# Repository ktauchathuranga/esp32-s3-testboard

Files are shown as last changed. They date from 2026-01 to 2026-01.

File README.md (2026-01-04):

# ESP32-S3 Test Board

A custom-designed development board for the ESP32-S3, designed in KiCad. This project was created for learning and prototyping purposes, featuring USB-C connectivity and a compact form factor.

<p align="center">
  <img src="/esp32-s3-testboard/esp32-s3-testboard.png" alt="3D Front View"">
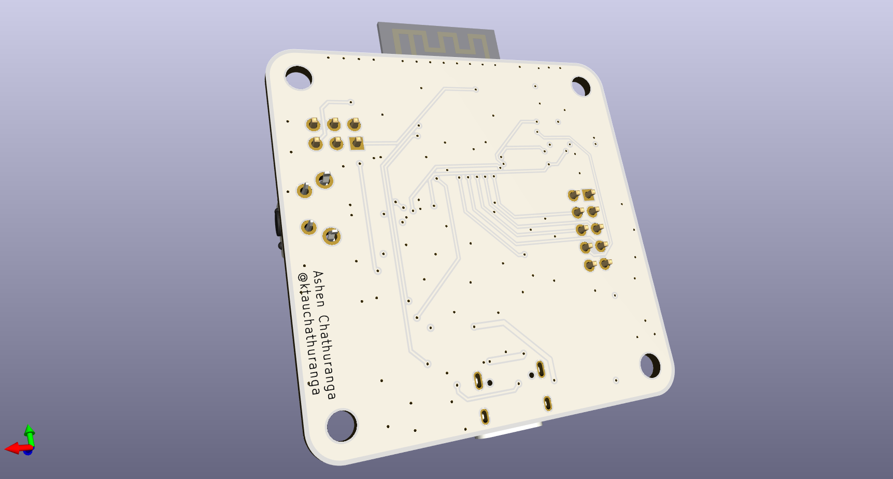
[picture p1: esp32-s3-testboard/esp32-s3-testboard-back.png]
3D Back View
  
</p>

## About The Project

This PCB is a breakout and test board for the **ESP32-S3** microcontroller. It breaks out the necessary pins for prototyping and includes essential circuitry for power management and programming.

The design is based on the [High Speed PCB Design tutorial by Made by Morten](https://www.youtube.com/watch?v=QoU0WWNgO2g).

### Key Features
* **Microcontroller:** ESP32-S3 (WROOM Module)
* **Connectivity:** USB Type-C (Native USB)
* **Power:** Onboard 3.3V LDO Regulator
* **User Interface:** Reset & Boot buttons, Status LEDs
* **Layer Stack:** 4-Layer PCB design for better signal integrity and power distribution

## EDA Tool & Libraries

* **Designed in:** [KiCad EDA](https://www.kicad.org/)
* **Custom Library:** This project utilizes specific footprints and symbols from my personal library:
    * [Oddibits - KiCad Library](https://github.com/ktauchathuranga/oddibits)

## Getting Started

To view or modify the design:

1.  Clone this repository:
    ```bash
    git clone https://github.com/ktauchathuranga/esp32-s3-testboard.git
    ```
2.  Clone the dependency library (Oddibits) alongside it or add it to your KiCad Global Libraries table:
    ```bash
    git clone https://github.com/ktauchathuranga/oddibits.git
    ```
3.  Open the `.kicad_pro` file in KiCad 7.0 or later.

## Fabrication

This board is designed to be manufactured by standard PCB fabrication houses (e.g., JLCPCB, PCBWay).
* **Layers:** 4
* **Minimum Trace/Space:** Check Design Rules (usually 0.2mm or similar standard capabilities)
* **Via Size:** Standard

## Credits & References

* **Original Guide:** [Made by Morten - ESP32-S3 PCB Design](https://www.youtube.com/watch?v=QoU0WWNgO2g)
* **Espressif Systems:** For the ESP32-S3 Datasheets and Hardware Design Guidelines.

## License

This project is open-source. Please see the [LICENSE](LICENSE) file for more details.

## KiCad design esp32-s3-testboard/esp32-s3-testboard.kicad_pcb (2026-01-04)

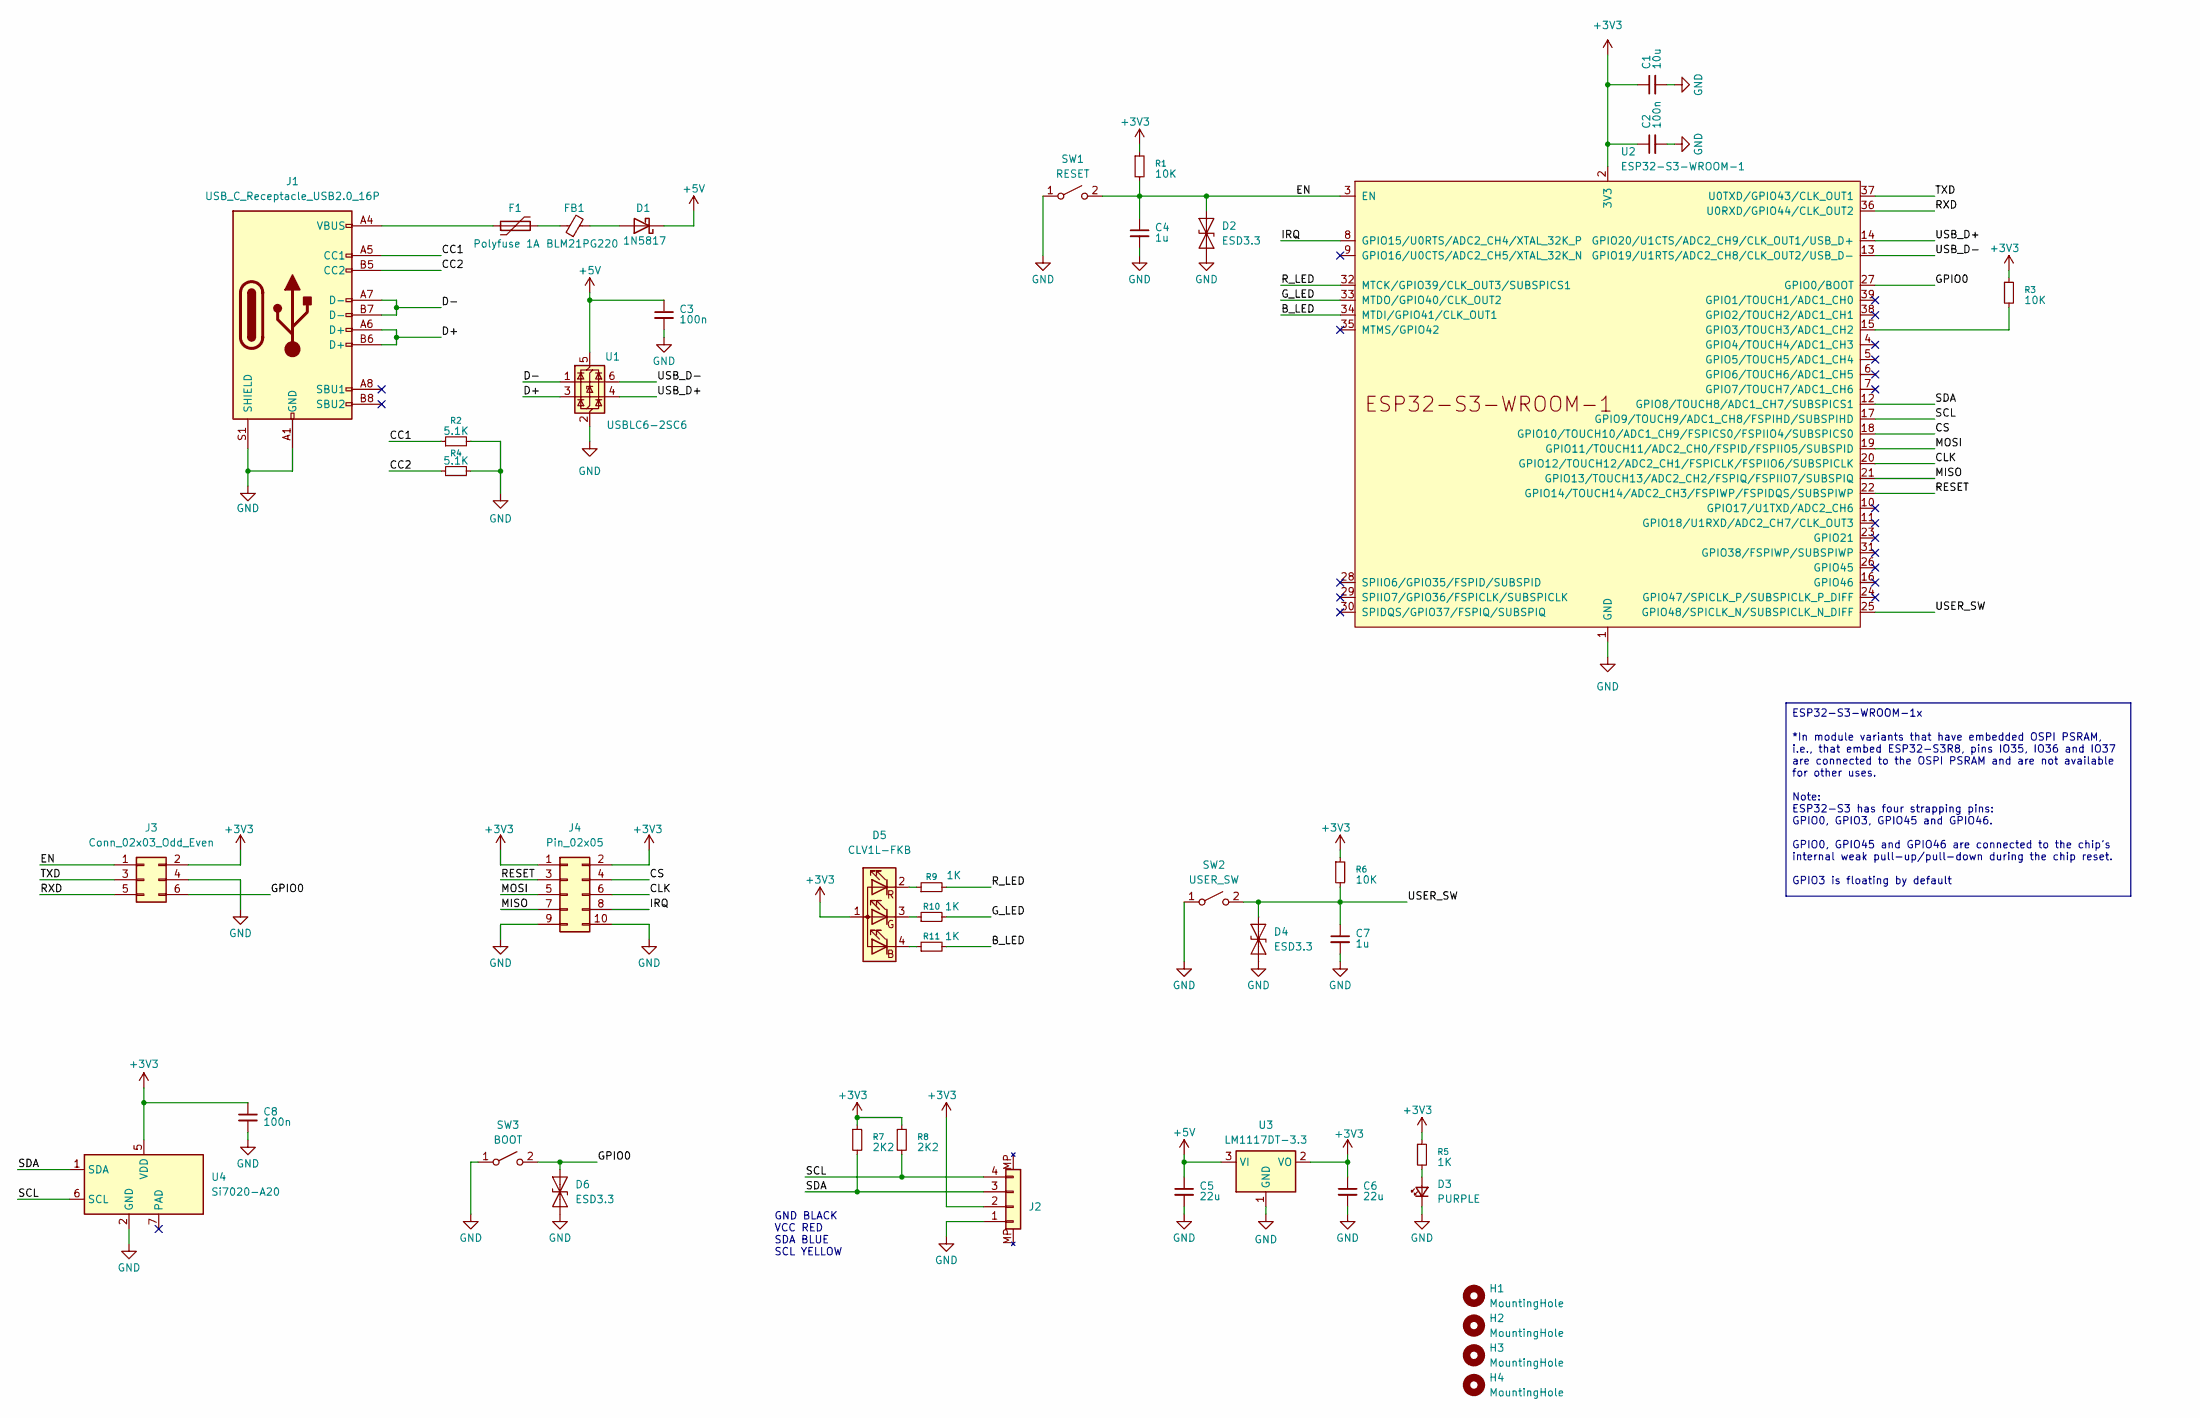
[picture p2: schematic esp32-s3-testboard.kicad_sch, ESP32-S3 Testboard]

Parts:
C1: 10u; C_0603_1608Metric
C2, C3, C8: 100n; C_0402_1005Metric
C4, C7: 1u; C_0603_1608Metric
C5, C6: 22u; C_0805_2012Metric
D1: 1N5817; D_SOD-123
D2, D4, D6: ESD3.3; D_SOD-923
D3: PURPLE; LED_0603_1608Metric
D5: CLV1L-FKB; LED_Cree-PLCC4_3.2x2.8mm_CCW
F1: Polyfuse 1A; Fuse_1206_3216Metric
FB1: BLM21PG220; L_0805_2012Metric
H1, H2, H3, H4: MountingHole; MountingHole_3.2mm_M3
J1: USB_C_Receptacle_USB2.0_16P; USB_C_Receptacle_GCT_USB4105-xx-A_16P_TopMnt_Horizontal
J2: JST_SH_SM04B-SRSS-TB_1x04-1MP_P1.00mm_Horizontal
J3: Conn_02x03_Odd_Even; PinHeader_2x03_P2.54mm_Vertical
J4: Pin_02x05; PinHeader_2x05_P2.54mm_Vertical
R1, R3, R6: 10K; R_0402_1005Metric
R2, R4: 5.1K; R_0402_1005Metric
R5, R9, R10, R11: 1K; R_0402_1005Metric
R7, R8: 2K2; R_0402_1005Metric
SW1: RESET; SW_SPST_B3U-1100P
SW2: USER_SW; SW_Tactile_SPST_Angled_PTS645Vx31-2LFS
SW3: BOOT; SW_SPST_B3U-1100P
U1: USBLC6-2SC6; SOT-23-6
U2: ESP32-S3-WROOM-1
U3: LM1117DT-3.3; SOT-223-3_TabPin2
U4: Si7020-A20; DFN-6-1EP_3x3mm_P1mm_EP1.5x2.4mm

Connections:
+3V3: C1.1, C2.1, C6.1, C8.1, D5.1 (A), J2.2, J3.2, J4.1, J4.2, R1.1, R3.1, R5.1, R6.1, R7.1, R8.1, U2.2 (3V3), U3.2 (VO), U4.5 (VDD); also elsewhere on the board
+5V: C3.1, C5.1, D1.1 (K), U1.5 (VBUS), U3.3 (VI)
/B_LED: R11.2, U2.34 (MTDI/GPIO41/CLK_OUT1)
/CC1: J1.A5 (CC1), R2.1
/CC2: J1.B5 (CC2), R4.1
/CLK: J4.6, U2.20 (GPIO12/TOUCH12/ADC2_CH1/FSPICLK/FSPIIO6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)
/CS: J4.4, U2.18 (GPIO10/TOUCH10/ADC1_CH9/FSPICS0/FSPIIO4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)
/D+: J1.A6 (D+), J1.B6 (D+), U1.3 (I/O2)
/D-: J1.A7 (D-), J1.B7 (D-), U1.1 (I/O1)
/EN: C4.1, D2.2 (A2), J3.1, R1.2, SW1.2 (B), U2.3 (EN); also elsewhere on the board
/GPIO0: D6.2 (A2), J3.6, SW3.2 (B), U2.27 (GPIO0/BOOT); also elsewhere on the board
/G_LED: R10.2, U2.33 (MTDO/GPIO40/CLK_OUT2)
/IRQ: J4.8, U2.8 (GPIO15/U0RTS/ADC2_CH4/XTAL_32K_P)
/MISO: J4.7, U2.21 (GPIO13/TOUCH13/ADC2_CH2/FSPIQ/FSPIIO7/S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)
/MOSI: J4.5, U2.19 (GPIO11/TOUCH11/ADC2_CH0/FSPID/FSPIIO5/S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)
/RESET: J4.3, U2.22 (GPIO14/TOUCH14/ADC2_CH3/FSPIWP/FSPIDQS/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)
/RXD: J3.5, U2.36 (U0RXD/GPIO44/CLK_OUT2); also elsewhere on the board
/R_LED: R9.2, U2.32 (MTCK/GPIO39/CLK_OUT3/SUBSPICS1)
/SCL: J2.4, R8.2, U2.17 (GPIO9/TOUCH9/ADC1_CH8/FSPIHD/SUBSPIHD), U4.6 (SCL)
/SDA: J2.3, R7.2, U2.12 (GPIO8/TOUCH8/ADC1_CH7/SUBSPICS1), U4.1 (SDA)
/TXD: J3.3, U2.37 (U0TXD/GPIO43/CLK_OUT1); also elsewhere on the board
/USB_D+: U1.4 (I/O2), U2.14 (GPIO20/U1CTS/ADC2_CH9/CLK_OUT1/USB_D+)
/USB_D-: U1.6 (I/O1), U2.13 (GPIO19/U1RTS/ADC2_CH8/CLK_OUT2/USB_D-)
/USER_SW: C7.1, D4.2 (A2), R6.2, SW2.2 (B), U2.25 (GPIO48/SPICLK_N/SUBSPICLK_N_DIFF)
GND: C1.2, C2.2, C3.2, C4.2, C5.2, C6.2, C7.2, C8.2, D2.1 (A1), D3.1 (K), D4.1 (A1), D6.1 (A1), J1.A1 (GND), J1.A12 (GND), J1.B1 (GND), J1.B12 (GND), J1.S1 (SHIELD), J2.1, J3.4, J4.9, J4.10, R2.2, R4.2, SW1.1 (A), SW2.1 (A), SW3.1 (A), U1.2 (GND), U2.1 (GND), U2.40 (GND), U2.41 (GND), U3.1 (GND), U4.2 (GND); also elsewhere on the board
unnamed: D1.2 (A), FB1.2
unnamed: D3.2 (A), R5.2
unnamed: D5.4 (BK), R11.1
unnamed: D5.3 (GK), R10.1
unnamed: D5.2 (RK), R9.1
unnamed: F1.1, J1.A4 (VBUS), J1.A9 (VBUS), J1.B4 (VBUS), J1.B9 (VBUS)
unnamed: F1.2, FB1.1
unnamed: R3.2, U2.15 (GPIO3/TOUCH3/ADC1_CH2)

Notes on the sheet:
GND BLACK VCC RED SDA BLUE SCL YELLOW
ESP32-S3-WROOM-1x *In module variants that have embedded OSPI PSRAM, i.e., that embed ESP32-S3R8, pins IO35, IO36 and IO37 are connected to the OSPI PSRAM and are not available for other uses. Note: ESP32-S3 has four strapping pins: GPIO0, GPIO3, GPIO45 and GPIO46. GPIO0, GPIO45 and GPIO46 are conn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

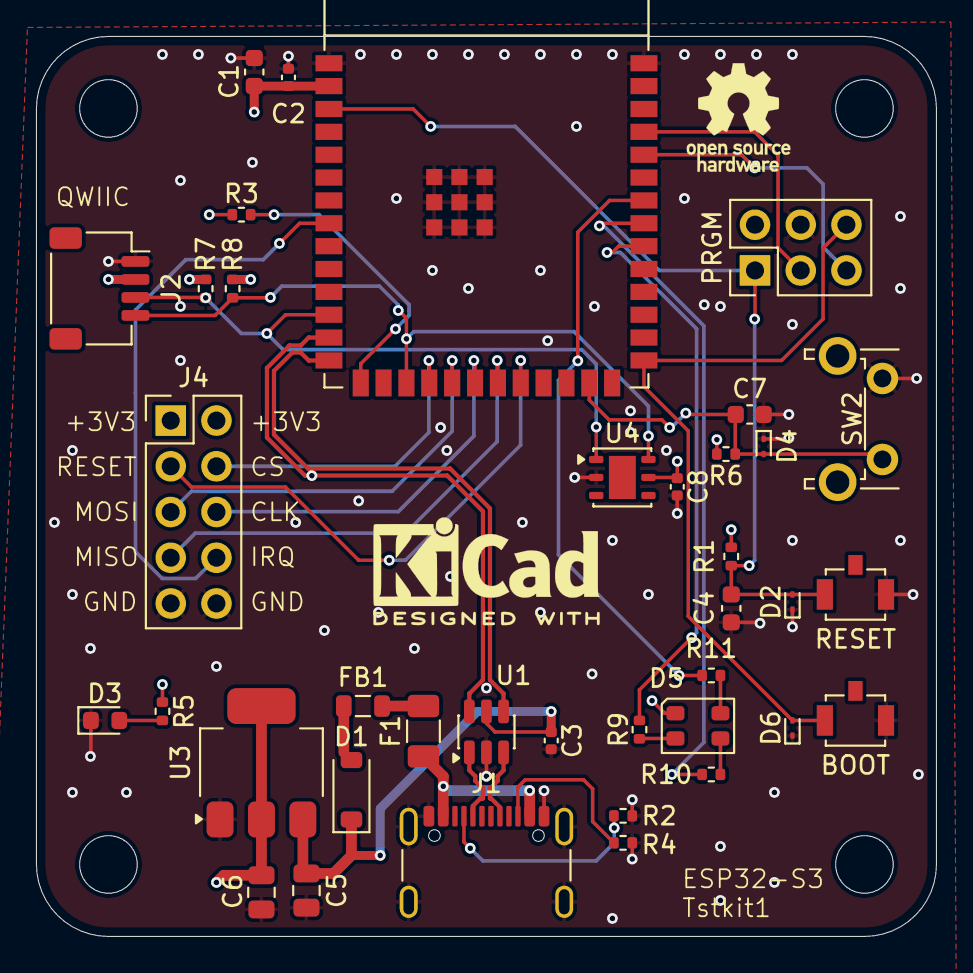
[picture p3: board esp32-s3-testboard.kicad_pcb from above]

Board: 4 copper layers, 50.0 x 50.0 mm, 42 parts (0 on the bottom side), 33 nets.

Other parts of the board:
BOOT: BOOT; SW_SPST_B3U-1100P
PRGM: Conn_02x03_Odd_Even; PinHeader_2x03_P2.54mm_Vertical
RESET: RESET; SW_SPST_B3U-1100P

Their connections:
+3V3: PRGM.2; also elsewhere on the board
/EN: PRGM.1, RESET.2 (B); also elsewhere on the board
/GPIO0: BOOT.2 (B), PRGM.6; also elsewhere on the board
/RXD: PRGM.5; also elsewhere on the board
/TXD: PRGM.3; also elsewhere on the board
GND: BOOT.1 (A), PRGM.4, RESET.1 (A); also elsewhere on the board

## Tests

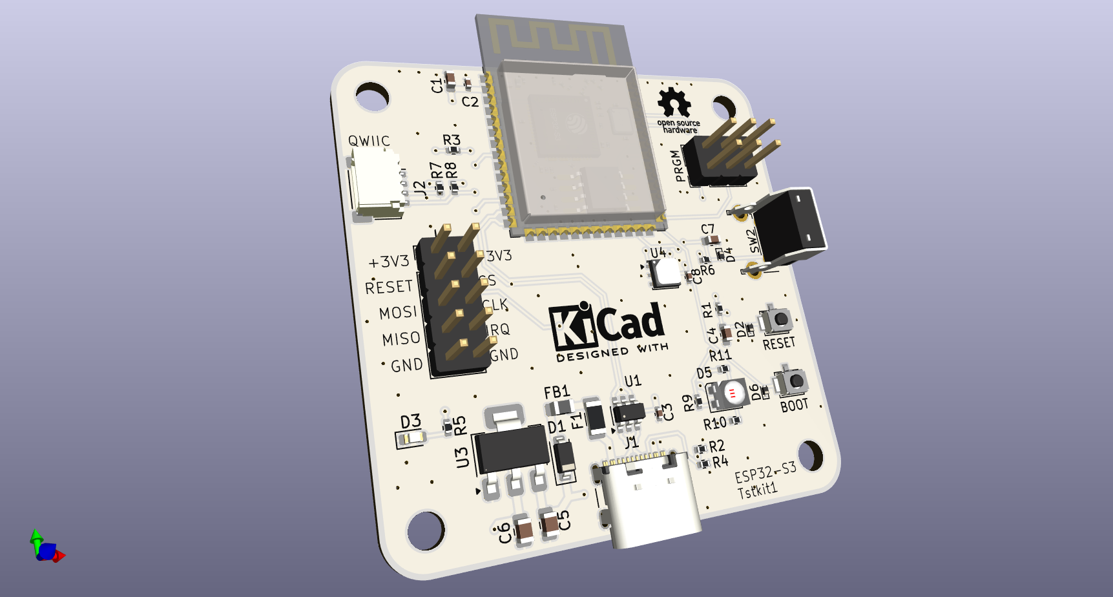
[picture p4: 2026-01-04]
esp32-s3-testboard/esp32-s3-testboard.png
